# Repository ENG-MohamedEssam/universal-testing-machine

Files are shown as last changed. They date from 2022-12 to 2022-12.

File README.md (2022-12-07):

# universal-testing-machine

## **Abstract**
#### This projet at first was about Reverse-Engineering a Stress/Strain analysis machine, then fix it and Automate it's process.
#### The following is an image of the machine 
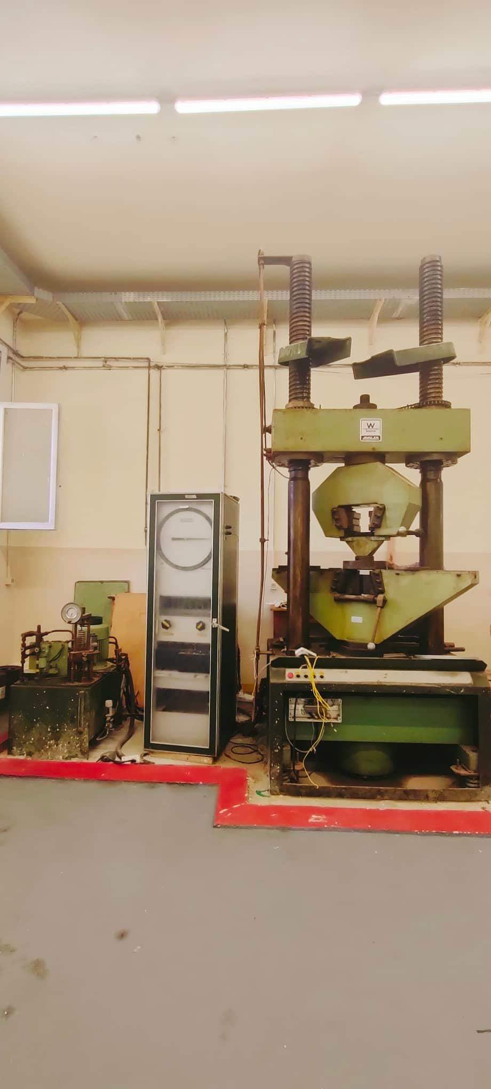
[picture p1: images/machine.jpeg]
Machine


#### Every part of the machine was Reverse-Engineered from the boards to the hydraulics to the classic control.
#### The following is an image of one of the Reverse-Engineered boards which was mine to Reverese-Engineer.
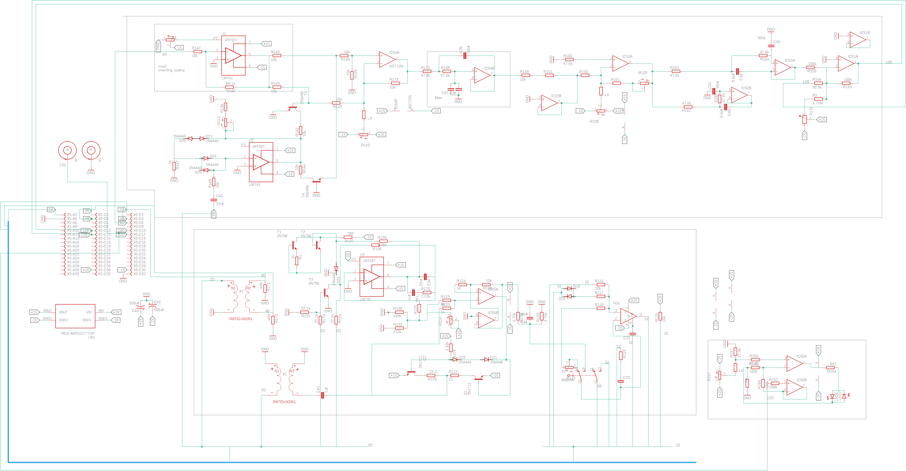
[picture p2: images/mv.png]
Board

#### I reverse Engineered The MV3058

#### Due to financial and permits issues the project was turned to be a prototype working with Embedded Systems.

#### The following is an image of the Prototype
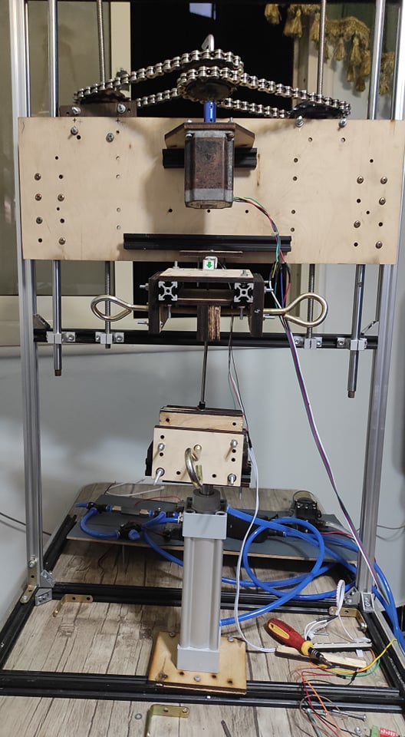
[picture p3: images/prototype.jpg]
prototype


#### The boards were desiged as follows, one board for the control, the second as a relay module. 

## **How the prototype works?**
 
#### The prototype mainly does exactly what the original machine does but on a smaller scale.
#### we mainly put a specimen between the two grippers and the machine puts tension or compression on the specimen till it breaks 
#### then it draws the Stress/Strain curves of the specimen's material.
#### It has a stepper motor used to adjust the place of the speciment, 
#### a piston that's derived by a hydraulic pump, 
#### a gripper used to grab the specimen.
#### As far as the Embedded systems part is concerend the machine had mainly 2 sensors ,
#### The Load Cell that's used to measure the Force and the Linear potentiometer that's used to measer the delta L.
#### the prototype is based mainly on two equations, Stress equation and Strain equation.
#### σ = F/A   ,    ε = δ/L  
#### the only two variables in these equations are the Force and the change in the length 

#### The following is images of the boards and panel.
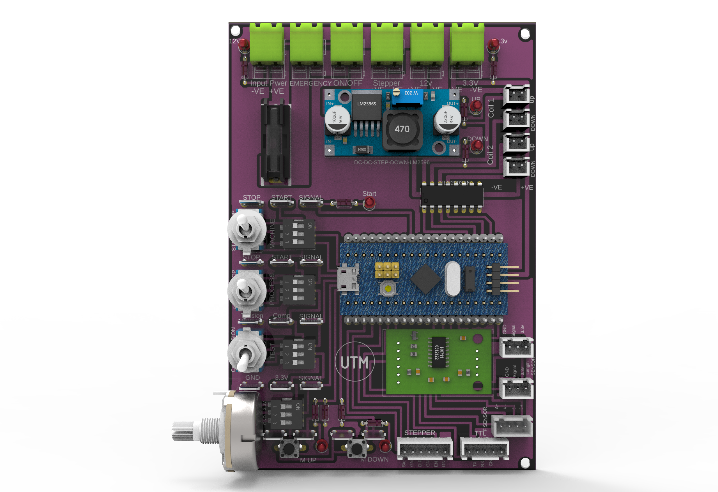
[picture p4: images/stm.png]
board

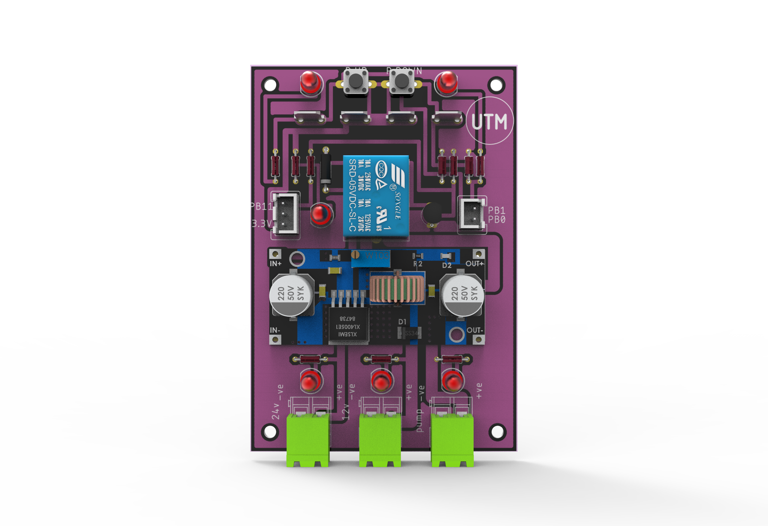
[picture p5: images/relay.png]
relay

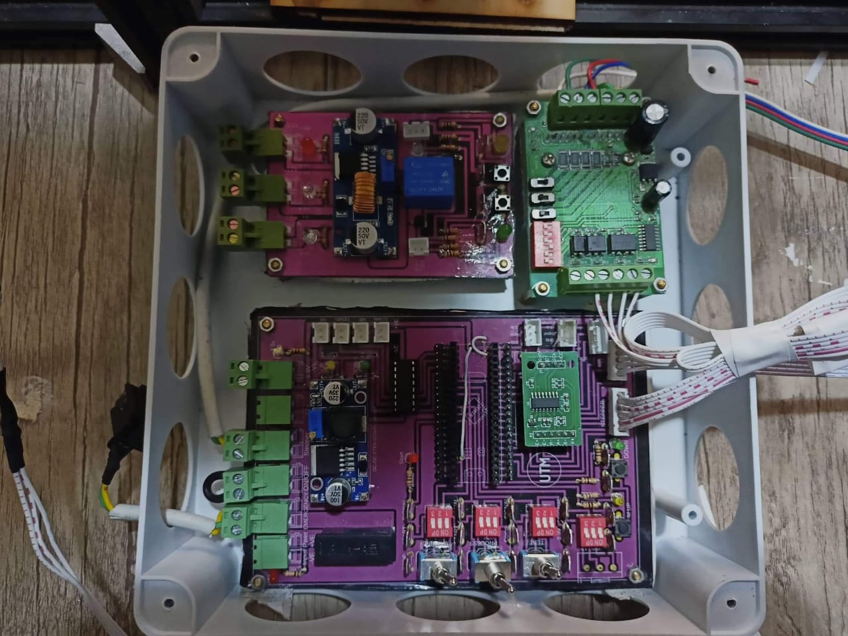
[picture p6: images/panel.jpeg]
panel


#### The follwing is Single Line Diagram that was made by me , it'll give you a good overview of all the Hardware connections in the panel
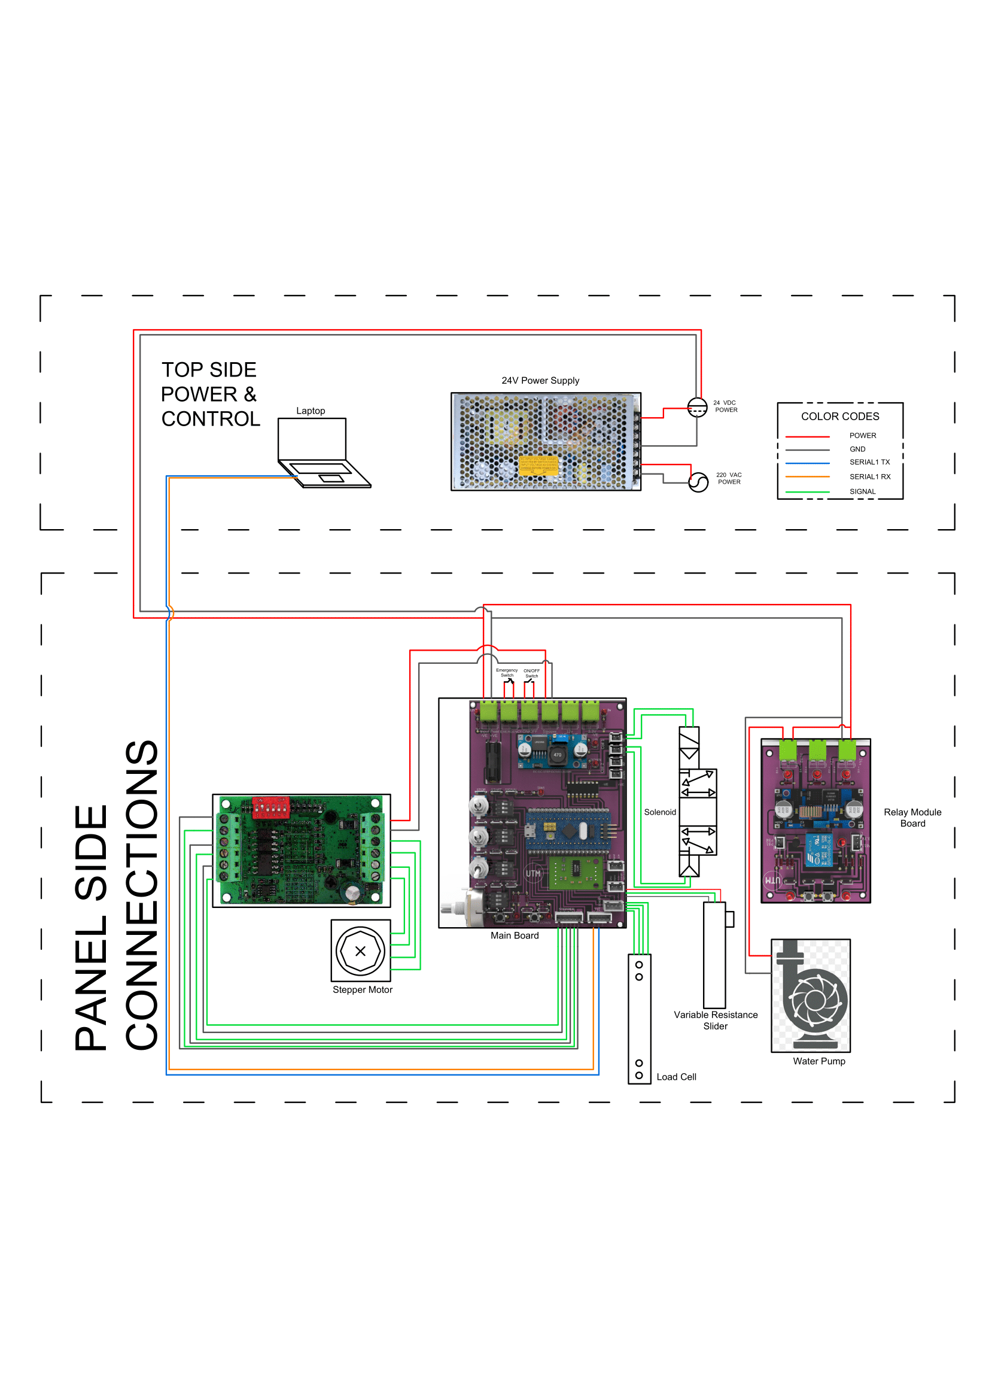
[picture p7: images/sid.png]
SID


#### The following link has some small SolidWorks parts that i've made for the machine whether it was as a specimen or for the sensors housings 
#### [parts](https://github.com/ENG-MohamedEssam/universal-testing-machine/tree/main/other-files/parts)

#### The following link has an explanation of the Embedded systems part explained by me 
#### [Explanation](https://drive.google.com/file/d/1bGaOVOjb-tQGSpPLI7ITkfYBf-VQDN8E/view)

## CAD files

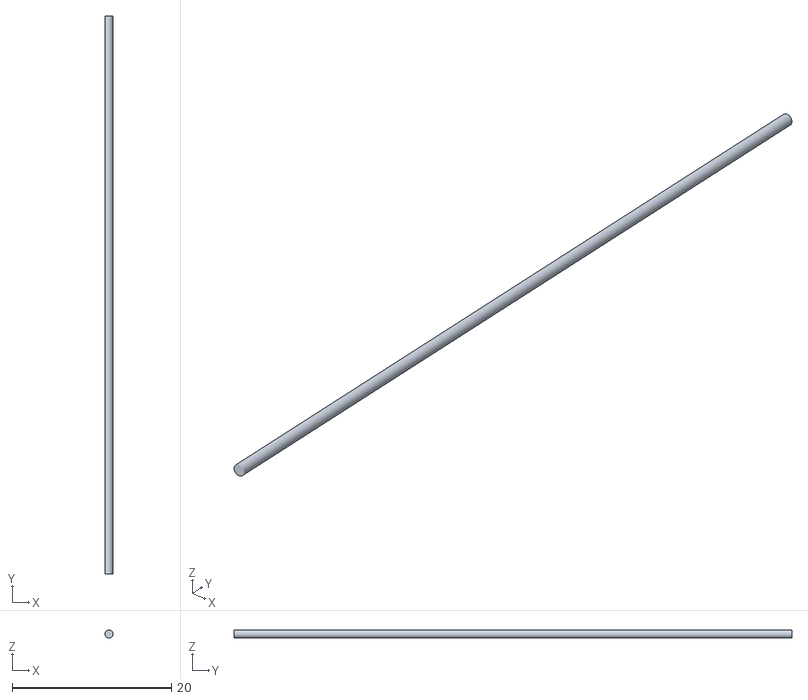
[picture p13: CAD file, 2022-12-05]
other-files/parts/Speciment round 7cm - 1mm.STL
0.999 x 70.0 x 1.00

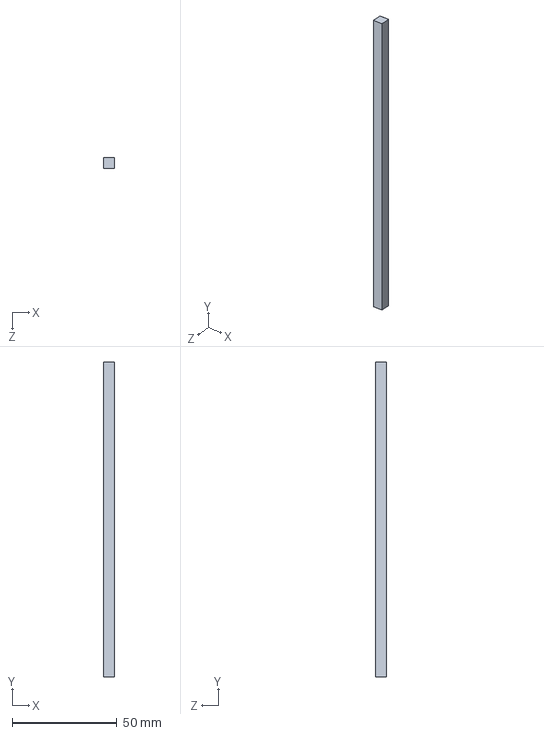
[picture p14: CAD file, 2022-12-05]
other-files/parts/Sample.SLDPRT
5.00 x 150.0 x 5.00 mm

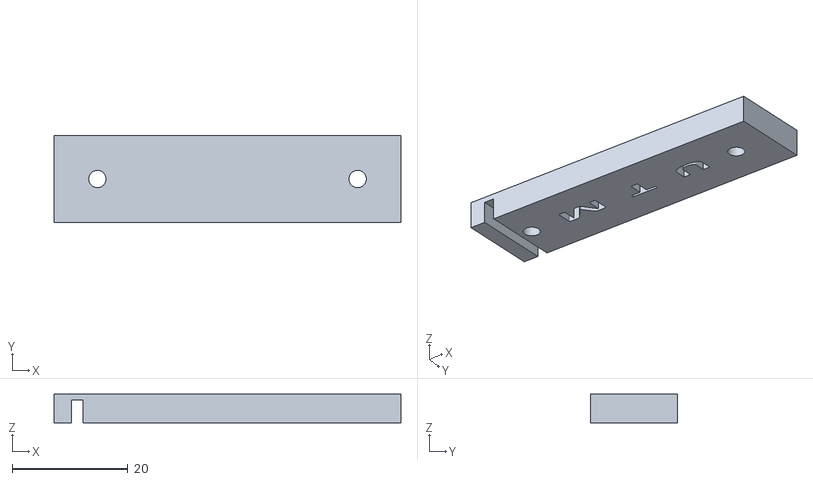
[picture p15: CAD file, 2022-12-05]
other-files/parts/UTM1.STL
60.0 x 15.0 x 5.00

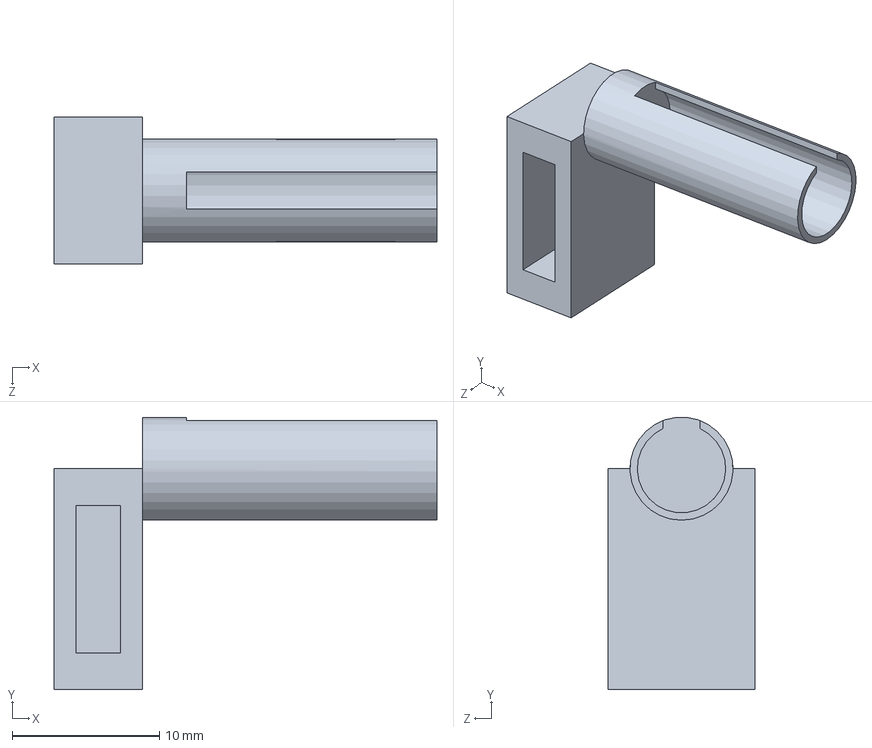
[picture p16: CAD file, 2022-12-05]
other-files/parts/LsensorHolder.SLDPRT
26.0 x 18.5 x 10.0 mm

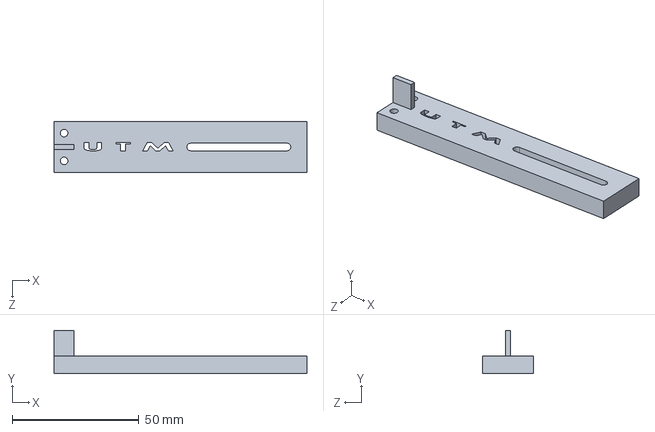
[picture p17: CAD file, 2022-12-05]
other-files/parts/Part2.SLDPRT
100.0 x 17.0 x 20.0 mm

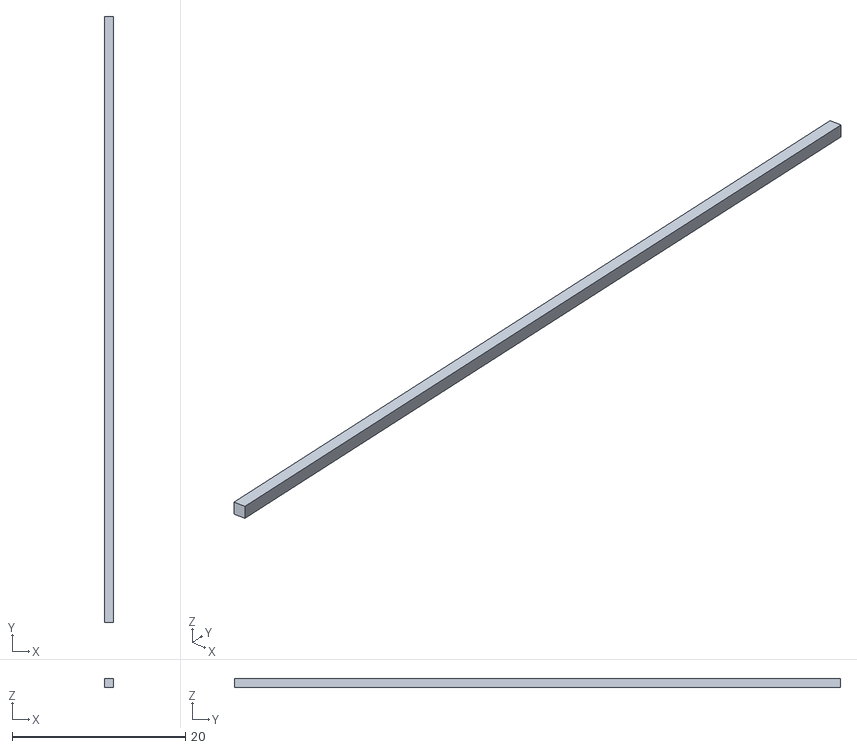
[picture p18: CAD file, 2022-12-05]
other-files/parts/Speciment square 7cm - 1mm.STL
1.00 x 70.0 x 1.00

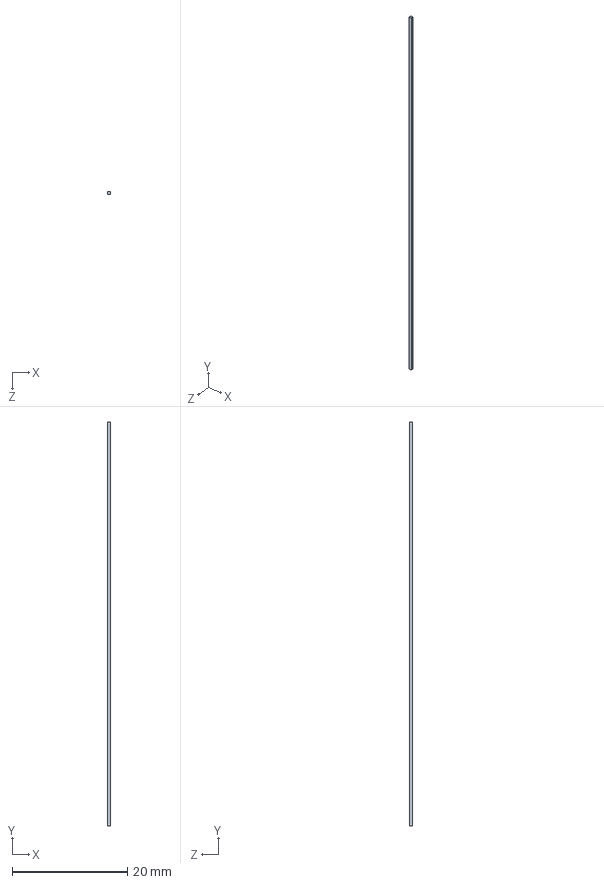
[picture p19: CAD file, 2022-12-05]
other-files/parts/Speciment round 7cm.SLDPRT
0.5 x 70.0 x 0.5 mm

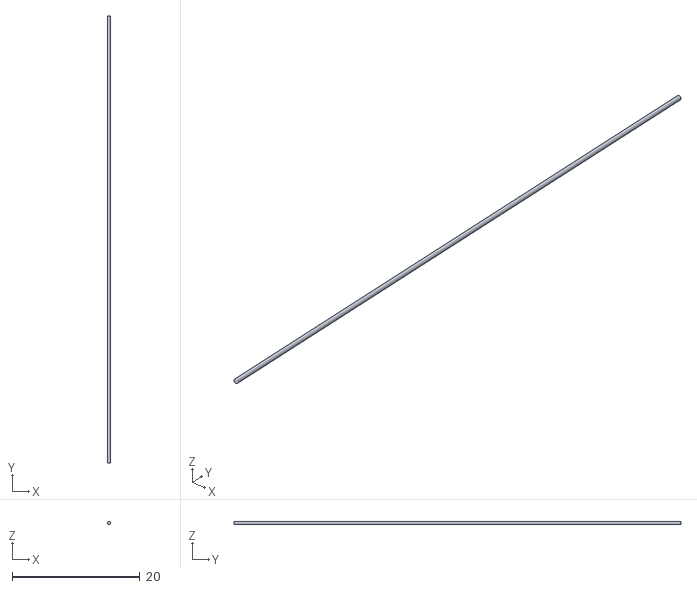
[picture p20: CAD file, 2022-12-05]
other-files/parts/Speciment round 7cm - 0.5mm .STL
0.5 x 70.0 x 0.5

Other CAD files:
other-files/SID.dwg
other-files/parts/Sample2.STL
other-files/parts/LsensorHolder.STL
other-files/parts/Part2.STL
other-files/parts/Sample.STL
other-files/parts/Speciment round 7cm - 0.5mm.STL

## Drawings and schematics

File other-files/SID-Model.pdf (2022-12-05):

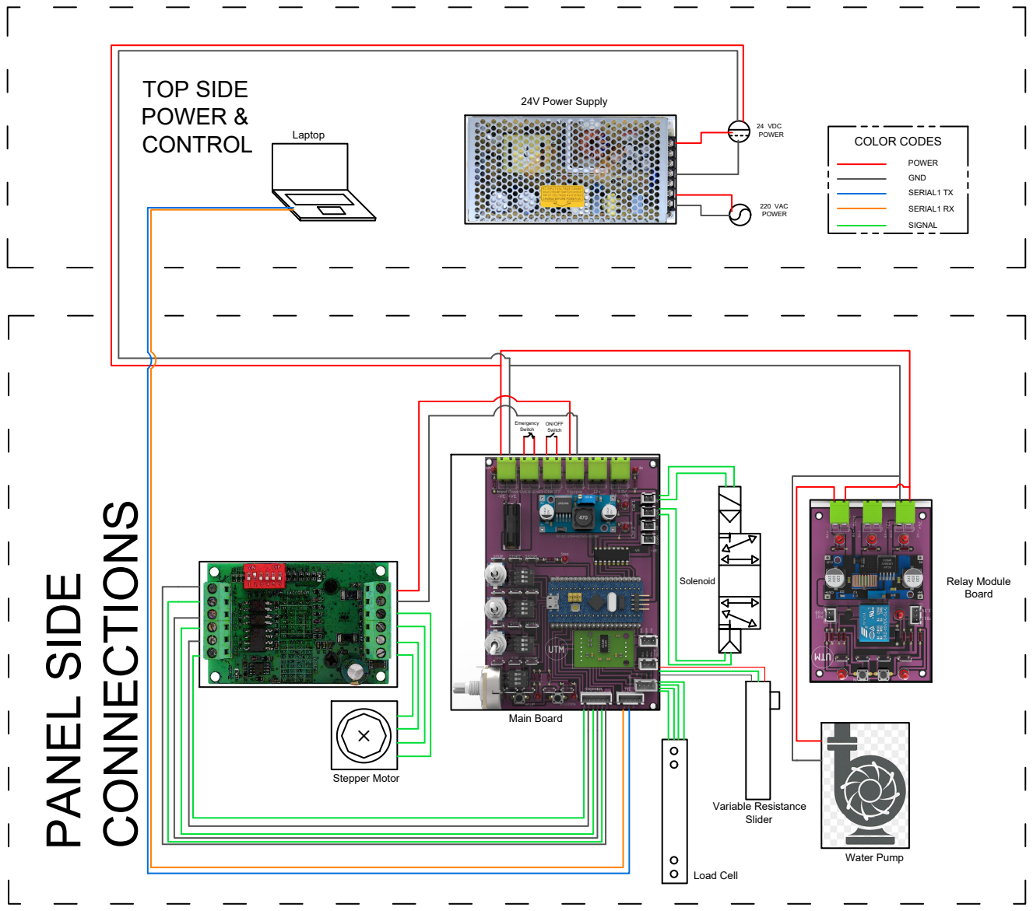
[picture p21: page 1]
COLOR CODES; POWER GND; SERIAL1 TX; SERIAL1 RX; 220 VAC; 24 VDC; TOP SIDE POWER &; Stepper Motor; Load Cell Variable Resistance Slider; Water Pump Main Board; Emergency Switch; ON/OFF Switch; 24V Power Supply

POWER PANEL SIDE CONNECTIONS

Relay Module Board Solenoid

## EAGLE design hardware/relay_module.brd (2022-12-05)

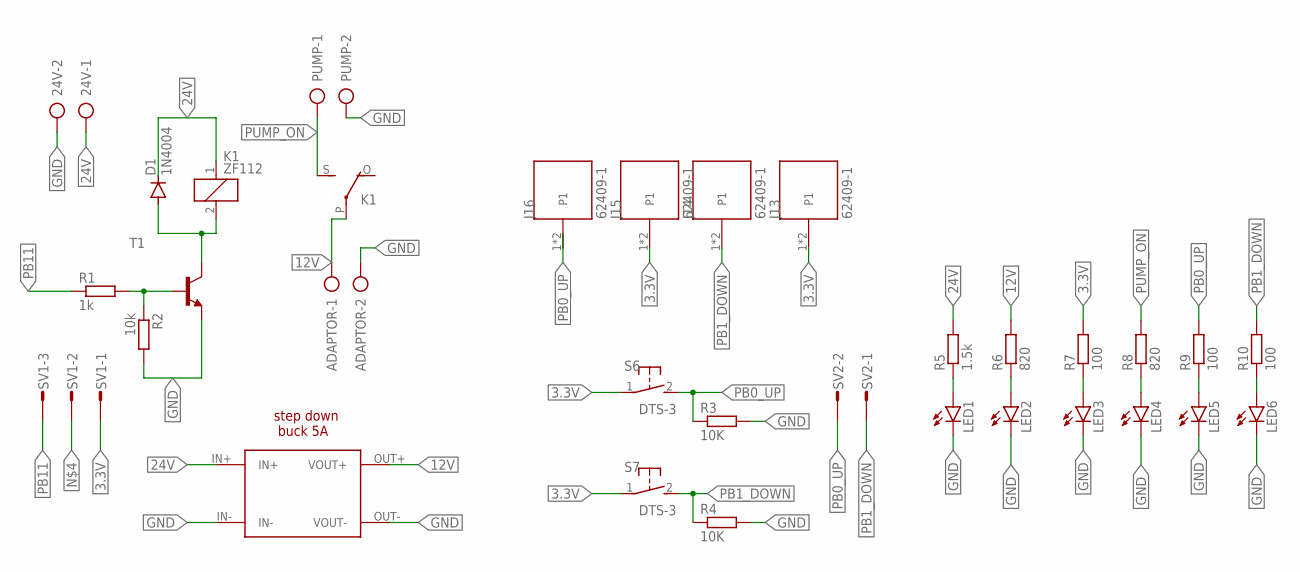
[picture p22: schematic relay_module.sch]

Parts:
24V: AK300/2
ADAPTOR: AK300/2
D1: 1N4004; DO41-10
J13, J14, J15, J16: 62409-1; TE_62409-1
K1: ZF112
LED1, LED2, LED3, LED4, LED5, LED6: LED5MM
PUMP: AK300/2
R1: 1k; 0204/7
R2: 10k; 0204/7
R3, R4: 10K; 0204/7
R5: 1.5k; 0204/7
R6, R8: 820; 0204/7
R7, R9, R10: 100; 0204/7
S6, S7: DTS-3
SV1: CON-AMP-MT_S03P
SV2: CON-AMP-MT_S02P
T1: 2N2222-NPN-TO92-EBC; TO92-EBC
U$1: BUCK_5A

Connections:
3.3V: J13.1, J13.2, J15.1, J15.2, R7.2, S6.1, S7.1, SV1.1
12V: ADAPTOR.1, K1.P, R6.2, U$1.OUT+ (VOUT+)
24V: 24V.1, D1.C, K1.1, R5.2, U$1.IN+
GND: 24V.2, ADAPTOR.2, LED1.K (C), LED2.K (C), LED3.K (C), LED4.K (C), LED5.K (C), LED6.K (C), PUMP.2, R2.2, R3.2, R4.2, T1.E, U$1.IN-, U$1.OUT- (VOUT-)
unnamed: R1.2, R2.1, T1.B
unnamed: LED1.A, R5.1
unnamed: D1.A, K1.2, T1.C
unnamed: LED2.A, R6.1
unnamed: LED5.A, R9.1
unnamed: LED3.A, R7.1
unnamed: LED4.A, R8.1
unnamed: LED6.A, R10.1
PB0_UP: J16.1, J16.2, R3.1, R9.2, S6.2, SV2.2
PB1_DOWN: J14.1, J14.2, R4.1, R10.2, S7.2, SV2.1
PB11: R1.1, SV1.3
PUMP_ON: K1.S, PUMP.1, R8.2

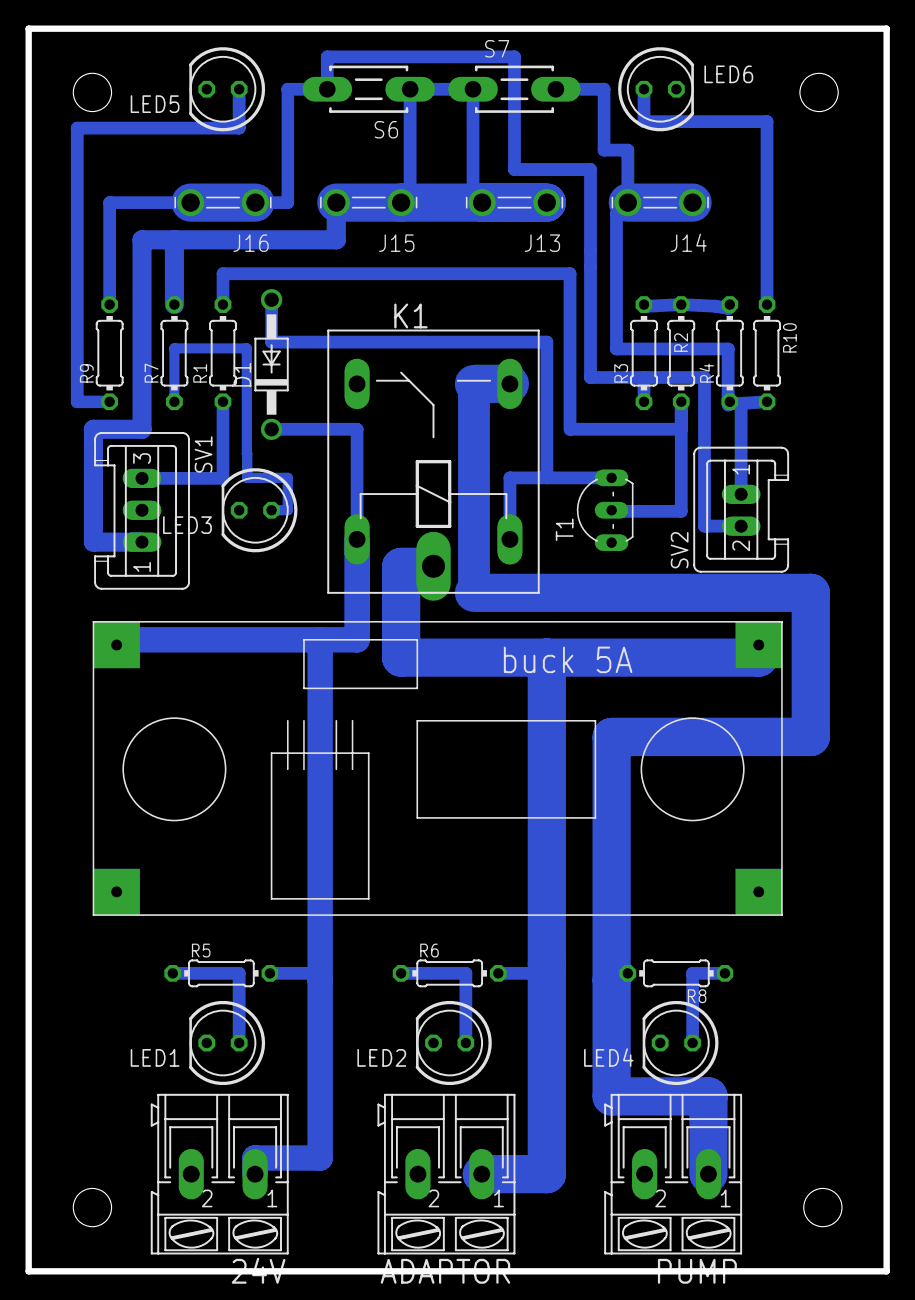
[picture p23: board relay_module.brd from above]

Board: 2 copper layers, 67.3 x 97.5 mm, 31 parts (0 on the bottom side), 16 nets.

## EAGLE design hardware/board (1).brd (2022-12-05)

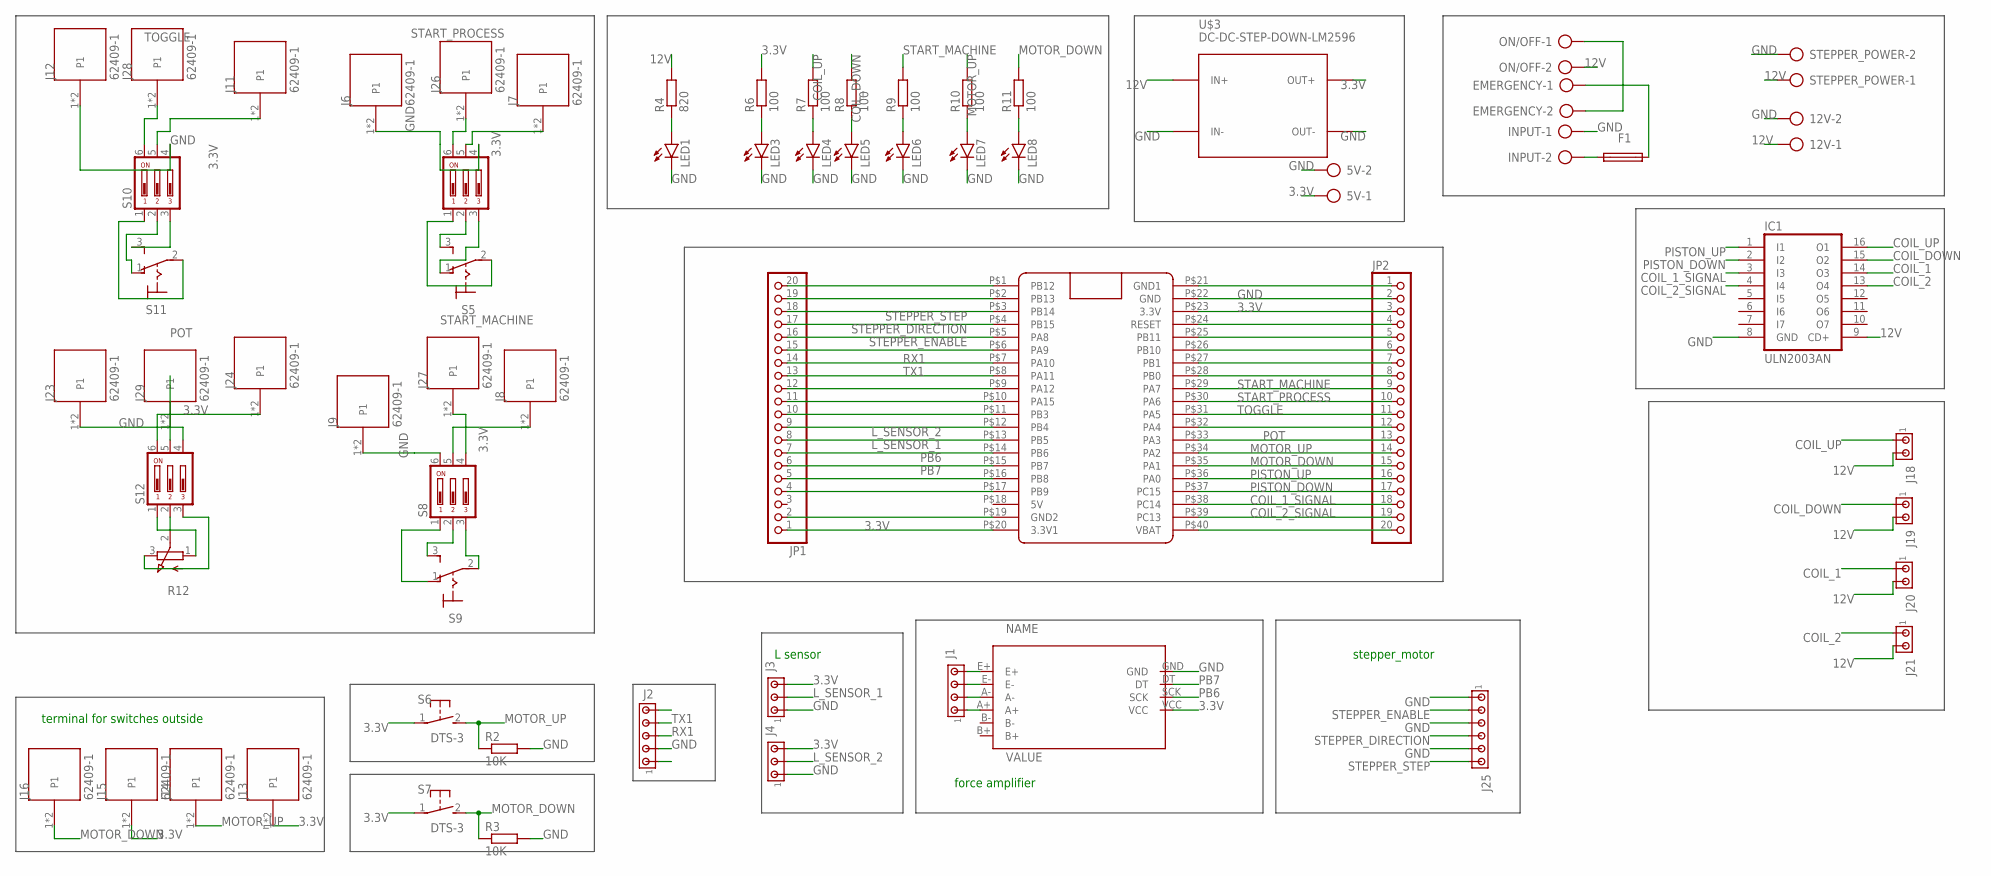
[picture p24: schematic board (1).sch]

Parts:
5V, 12V: AK300/2
EMERGENCY: AK300/2
F1: SH22
IC1: ULN2003AN; DIL16
INPUT: AK300/2
J1: MTA04-100; 10X04MTA
J2: MTA05-100; 10X05MTA
J3, J4: MTA03-100; 10X03MTA
J6, J7, J8, J9, J11, J12, J13, J14, J15, J16, J23, J24, J26, J27, J28, J29: 62409-1; TE_62409-1
J18, J19, J20, J21: MTA02-100; 10X02MTA
J25: MTA06-100; 10X06MTA
JP1, JP2: PINHD-1X20; 1X20
LED1, LED3, LED4, LED5, LED6, LED7, LED8: LED3MM
ON/OFF: AK300/2
R2, R3: 10K; 0204/7
R4: 820; 0204/7
R6, R7, R8, R9, R10, R11: 100; 0204/7
R12: 3RP/1610N
S4, S8, S10, S12: DP03; DP-03
S5, S9, S11: 320-916
S6, S7: DTS-3
STEPPER_POWER: AK300/2
U$1: BLUE_PILL
U$2: HX711A; HX711
U$3: DC-DC-STEP-DOWN-LM2596

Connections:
3.3V: 5V.1, J3.3, J4.3, J7.1, J7.2, J8.1, J8.2, J11.1, J11.2, J13.1, J13.2, J15.1, J15.2, J24.1, J24.2, JP1.1, JP2.3, R6.2, S4.5, S6.1, S7.1, S8.5, S10.5, S12.6, U$1.P$20 (3.3V1), U$1.P$23 (3.3V), U$2.VCC, U$3.OUT+
12V: 12V.1, IC1.9 (CD+), J18.2, J19.2, J20.2, J21.2, ON/OFF.2, R4.2, STEPPER_POWER.1, U$3.IN+
COIL_1: IC1.14 (O3), J20.1
COIL_1_SIGNAL: IC1.3 (I3), JP2.18, U$1.P$38 (PC14)
COIL_2: IC1.13 (O4), J21.1
COIL_2_SIGNAL: IC1.4 (I4), JP2.19, U$1.P$39 (PC13)
COIL_DOWN: IC1.15 (O2), J19.1, R8.2
COIL_UP: IC1.16 (O1), J18.1, R7.2
GND: 5V.2, 12V.2, IC1.8 (GND), INPUT.1, J2.2, J3.1, J4.1, J6.1, J6.2, J9.1, J9.2, J12.1, J12.2, J23.1, J23.2, J25.1, J25.3, J25.5, JP1.2, JP2.2, LED1.K (C), LED3.K (C), LED4.K (C), LED5.K (C), LED6.K (C), LED7.K (C), LED8.K (C), R2.2, R3.2, S4.4, S8.6, S10.4, S12.4, STEPPER_POWER.2, U$1.P$19 (GND2), U$1.P$22 (GND), U$2.GND, U$3.IN-, U$3.OUT-
L_SENSOR_1: J3.2, JP1.8, U$1.P$13 (PB5)
L_SENSOR_2: J4.2, JP1.9, U$1.P$12 (PB4)
MOTOR_DOWN: J16.1, J16.2, JP2.15, R3.1, R11.2, S7.2, U$1.P$35 (PA1)
MOTOR_UP: J14.1, J14.2, JP2.14, R2.1, R10.2, S6.2, U$1.P$34 (PA2)
unnamed: J1.4, U$2.E+
unnamed: J1.3, U$2.E-
unnamed: J1.2, U$2.A-
unnamed: J1.1, U$2.A+
unnamed: LED1.A, R4.1
unnamed: LED3.A, R6.1
unnamed: LED4.A, R7.1
unnamed: LED5.A, R8.1
unnamed: LED6.A, R9.1
unnamed: LED7.A, R10.1
unnamed: LED8.A, R11.1
unnamed: F1.1, INPUT.2
unnamed: S4.1, S5.2
unnamed: S4.2, S5.3 (S)
unnamed: JP1.4, U$1.P$17 (PB9)
unnamed: JP1.5, U$1.P$16 (PB8)
unnamed: JP1.10, U$1.P$11 (PB3)
unnamed: JP1.11, U$1.P$10 (PA15)
unnamed: JP1.12, U$1.P$9 (PA12)
unnamed: JP1.13, U$1.P$8 (PA11)
unnamed: EMERGENCY.1, F1.2
unnamed: EMERGENCY.2, ON/OFF.1
unnamed: JP2.20, U$1.P$40 (VBAT)
unnamed: JP2.7, U$1.P$27 (PB1)
unnamed: JP2.8, U$1.P$28 (PB0)
unnamed: JP1.20, U$1.P$1 (PB12)
unnamed: JP1.19, U$1.P$2 (PB13)
unnamed: S4.3, S5.1 (O)
unnamed: S10.1, S11.2
unnamed: S8.3, S9.2
unnamed: S8.1, S9.1 (O)
unnamed: JP2.1, U$1.P$21 (GND1)
unnamed: JP2.4, U$1.P$24 (RESET)
unnamed: S8.2, S9.3 (S)
unnamed: S10.3, S11.3 (S)
unnamed: S10.2, S11.1 (O)
unnamed: JP2.6, U$1.P$26 (PB10)
unnamed: R12.3 (E), S12.3
unnamed: R12.1 (A), S12.1
unnamed: R12.2 (S), S12.2
unnamed: JP2.12, U$1.P$32 (PA4)
unnamed: JP2.5, U$1.P$25 (PB11)
PB6: JP1.7, U$1.P$14 (PB6), U$2.SCK
PB7: JP1.6, U$1.P$15 (PB7), U$2.DT
PISTON_DOWN: IC1.2 (I2), JP2.17, U$1.P$37 (PC15)
PISTON_UP: IC1.1 (I1), JP2.16, U$1.P$36 (PA0)
POT: J29.1, J29.2, JP2.13, S12.5, U$1.P$33 (PA3)
RX1: J2.3, JP1.15, U$1.P$6 (PA9)
START_MACHINE: J27.1, J27.2, JP2.9, R9.2, S8.4, U$1.P$29 (PA7)
START_PROCESS: J26.1, J26.2, JP2.10, S4.6, U$1.P$30 (PA6)
STEPPER_DIRECTION: J25.4, JP1.17, U$1.P$4 (PB15)
STEPPER_ENABLE: J25.2, JP1.16, U$1.P$5 (PA8)
STEPPER_STEP: J25.6, JP1.18, U$1.P$3 (PB14)
TOGGLE: J28.1, J28.2, JP2.11, S10.6, U$1.P$31 (PA5)
TX1: J2.4, JP1.14, U$1.P$7 (PA10)

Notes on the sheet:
force amplifier
stepper_motor
L sensor
terminal for switches outside

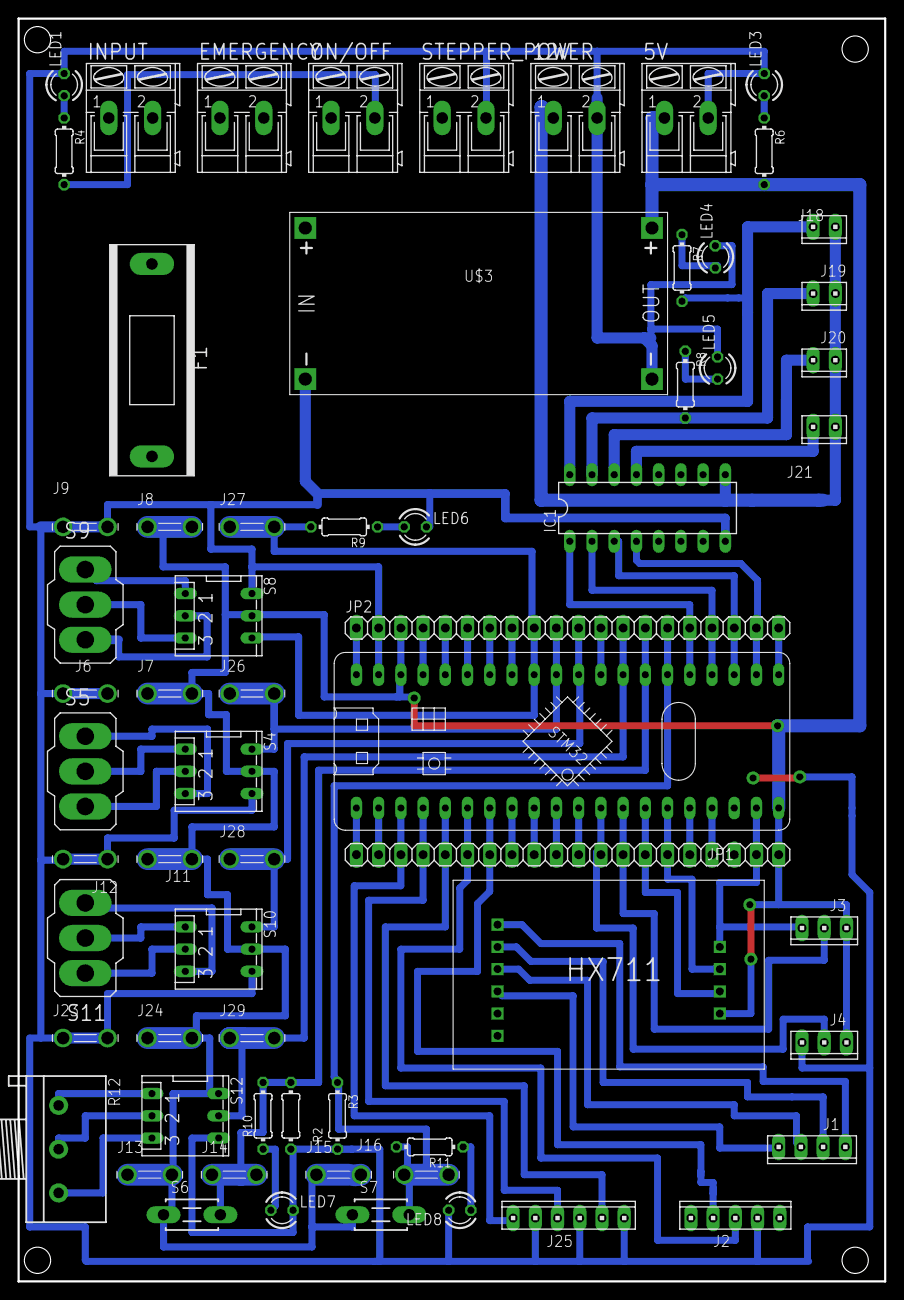
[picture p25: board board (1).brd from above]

Board: 2 copper layers, 99.0 x 144.3 mm, 64 parts (0 on the bottom side), 68 nets.

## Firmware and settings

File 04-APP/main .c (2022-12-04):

//*********************************************************************************/
/* Author    : Embedded system Sub team                                          */
/* Version   : V01                                                              */
/* Date      : 14 May 2020                                                     */
/******************************************************************************/

#include <stdio.h>
#include <stdlib.h>
#include "diag/Trace.h"


// Sample pragmas to cope with warnings. Please note the related line at
// the end of this function, used to pop the compiler diagnostics status.
#pragma GCC diagnostic push
#pragma GCC diagnostic ignored "-Wunused-parameter"
#pragma GCC diagnostic ignored "-Wmissing-declarations"
#pragma GCC diagnostic ignored "-Wreturn-type"
/******** includes Section **********/
#include "STD_TYPES.h"
#include "BIT_MATH.h"
#include "MCAL/RCC_interface.h"
#include "MCAL/DIO_interface.h"
#include "MCAL/USART_interface.h"
#include "MCAL/STK_interface.h"
#include "HAL/HX7111_force_sensor.h"
#include "HAL/STEPPER_HAL.h"
#include "MCAL/ADC_interface.h"
//------------------Macros---------
#define START_M             PIN7               // On or high (Toggle)     GPIOA
#define MOTOR_UP            PIN2               // normal push button      GPIOA
#define MOTOR_DOWN          PIN1               // normal push button      GPIOA
#define START_PROCESS       PIN6               //Toggle                   GPIOA
#define TOGGLE              PIN5               // tension or compression  GPIOA
#define PUMB_UP             PIN1               // pump (port B)
#define PUMB_DWON           PIN2               // pump (port B)
//-----------------------------
#define PISTON_UP      PIN0
#define PISTON_DOWN    PIN10
/*************************************/
//-----------------global variables -------
extern u8 global_u8ReceivedData;
float force;
float DeltaLength;
float Area = 125;   //mm2
float length = 70;   // meter
float Stress;
float Strain;
u8 X_axis[100];
u8 Y_axis[100];
int Gcount=0;
char breakpoint = 0;
char val1=0;
u8 flag=0;
/************************************/


/******************* Functions *********************/
void Fault_fun(void)
{
//	TOG_BIT(flag , 0);
//	MGPIO_VidSetPinValue(GPIOA,PIN10,flag);

}

void adjustmotor_UP()
{
	if(MGPIO_u8GetPinValue ( GPIOA , MOTOR_UP))
	{
		STEPPER_FORWARD(GPIOB, PIN14, GPIOB, PIN15,5000); //range time delay from 50 to 1000
	}

	else
	{
		STEPPER_stop(GPIOB, PIN14, GPIOB, PIN15);
	}
}


void adjustmotor_DOWN()
{

   if(MGPIO_u8GetPinValue ( GPIOA , MOTOR_DOWN))
	{
		STEPPER_REVERSE(GPIOB, PIN14, GPIOB, PIN15,5000);
	}
	else
	{
		STEPPER_stop(GPIOB, PIN14, GPIOB, PIN15);
	}
}


void selnoid_UP(){
 	MGPIO_VidSetPinValue(GPIOB, PISTON_UP, HIGH);
    MGPIO_VidSetPinValue(GPIOB, PISTON_DOWN, LOW);
    MSTK_voidSetBusyWait(300000);// 0.3 sec
 	MGPIO_VidSetPinValue(GPIOB, PISTON_UP, LOW);
    MGPIO_VidSetPinValue(GPIOB, PISTON_DOWN, LOW);
}
void selnoid_DWON(){
 	MGPIO_VidSetPinValue(GPIOB, PISTON_UP, LOW);
    MGPIO_VidSetPinValue(GPIOB, PISTON_DOWN, HIGH);
    MSTK_voidSetBusyWait(300000);// 0.3 sec
 	MGPIO_VidSetPinValue(GPIOB, PISTON_UP, LOW);
    MGPIO_VidSetPinValue(GPIOB, PISTON_DOWN, LOW);
}

void switches_int(void)
{

	MGPIO_VidSetPinDirection(GPIOA,START_M,INPUT_FLOATING);
	MGPIO_VidSetPinDirection(GPIOA,MOTOR_UP,INPUT_FLOATING);
	MGPIO_VidSetPinDirection(GPIOA,MOTOR_DOWN,INPUT_FLOATING);
	MGPIO_VidSetPinDirection(GPIOA,START_PROCESS,INPUT_FLOATING);
	MGPIO_VidSetPinDirection(GPIOA,TOGGLE,INPUT_FLOATING);

	MGPIO_VidSetPinDirection(GPIOA,PUMB_UP,INPUT_FLOATING);// NEW: port B
	MGPIO_VidSetPinDirection(GPIOA,PUMB_DWON,INPUT_FLOATING);

	MGPIO_VidSetPinDirection(GPIOA,PISTON_UP,OUTPUT_SPEED_10MHZ_PP); //for  pump Up
	MGPIO_VidSetPinDirection(GPIOB,PISTON_DOWN,OUTPUT_SPEED_10MHZ_PP);//for pump down

}

void Compression ()
{  	MGPIO_VidSetPinValue(GPIOB, PISTON_UP, HIGH);
MGPIO_VidSetPinValue(GPIOB, PISTON_DOWN, LOW);
MSTK_voidSetBusyWait(100);
force = ADC_u16ReadChannelPoll(1);
while(force>10 && MGPIO_u8GetPinValue(GPIOA,TOGGLE))
{

	force = ADC_u16ReadChannelPoll(1);
	DeltaLength = ADC_u16ReadChannelPoll(4);
	Stress  = force / Area;  //stress eqn
	Strain  = DeltaLength / length; // srain eqn
	X_axis[Gcount] = (char) Stress * 10;             //i.e. 1.4*10 = 14
	Y_axis[Gcount] = (char) Strain * 10;
	Gcount++;
}
for(int i=0; i<=Gcount; i++){
	MUSART1_voidTransmit(&X_axis[i],1);
	MUSART1_voidTransmit(&Y_axis[i],1);
}
Gcount =0 ;
breakpoint = 1;
}


void Tension(void)
{
	MGPIO_VidSetPinValue(GPIOB, PISTON_UP, LOW);
	MGPIO_VidSetPinValue(GPIOB, PISTON_DOWN, HIGH);
	MSTK_voidSetBusyWait(100);
	force = ADC_u16ReadChannelPoll(1);
	while(force>10 && MGPIO_u8GetPinValue(GPIOA,TOGGLE))
	{

		force = ADC_u16ReadChannelPoll(1);
		DeltaLength = ADC_u16ReadChannelPoll(4);
		Stress  = force / Area;  //stress eqn
		Strain  = DeltaLength / length; // srain eqn
		X_axis[Gcount] = (char) Stress * 10;             //i.e. 1.4*10 = 14
		Y_axis[Gcount] = (char) Strain * 10;
		Gcount++;
	}
	for(int i=0; i<=Gcount; i++){
		MUSART1_voidTransmit(&X_axis[i],1);
		MUSART1_voidTransmit(&Y_axis[i],1);
	}
	Gcount =0 ;
	breakpoint = 1;

}



int main(int argc, char* argv[])
{

	// init preigherals and clocks

	RCC_voidInitSysClock();
	RCC_voidEnableClock(RCC_APB2,2);  // clocks for port A
	RCC_voidEnableClock(RCC_APB2,3);  // clocks for port B
	RCC_voidEnableClock(RCC_APB2,9);  // clocks for ADC1
	RCC_voidEnableClock(RCC_APB2,14); // clocks for UART1
	MSTK_voidInit();
	ADC_VoidInit();
	MUSART1_voidInit();
	//--------------------------------
	/* Setting A9:TX pin as Output alternate function push pull w max speed 50 MHz */
	MGPIO_VidSetPinDirection(GPIOA,PIN9,OUTPUT_SPEED_50MHZ_AFPP);
	/* Setting A10:RX pin as input floating */
	MGPIO_VidSetPinDirection(GPIOA,PIN10,OUTPUT_SPEED_2MHZ_PP);
	STEPPER_void_init(GPIOB,PIN14,GPIOB,PIN15);
    switches_int();
	MUSART1_voidSetcallBack(Fault_fun);
	u8 Recive_USART=0;
	while(1)
	{
		if(MGPIO_u8GetPinValue(GPIOA,START_M)){



			if(MGPIO_u8GetPinValue(GPIOA,MOTOR_UP) || global_u8ReceivedData == 1U ){

				adjustmotor_UP();
			}
			else if(MGPIO_u8GetPinValue(GPIOA,MOTOR_DOWN) || global_u8ReceivedData == 2U){

				adjustmotor_DOWN();
			}
			else if(MGPIO_u8GetPinValue(GPIOA,PUMB_UP) || global_u8ReceivedData == 3U){

				selnoid_UP();
			}
			else if(MGPIO_u8GetPinValue(GPIOA,PUMB_DWON) || global_u8ReceivedData == 4U){

				selnoid_DWON();
			}
			else if(MGPIO_u8GetPinValue(GPIOA,TOGGLE) || global_u8ReceivedData == 5U){   //Say compression

				Compression();
			}
			else if(!MGPIO_u8GetPinValue(GPIOA,TOGGLE) || global_u8ReceivedData == 6U){   //Say tension

					Tension();
			}

			else {
                   //Do nothing
			}





		}

	}



}
#pragma GCC diagnostic pop

//
// Recive_USART = MUSART1_u8Receive();
//		switch(Recive_USART){
//		case 1:
//			adjustmotor_UP();    // Move Stepper motor Up
//			break;
//		case 2:
//			adjustmotor_DWON();  // Move Stepper motor Up
//			break;
//		case 3:
//			break;
//		case 4:
//			break;
//		case 5:
//			break;
//
//
//
//
//
//	     	}

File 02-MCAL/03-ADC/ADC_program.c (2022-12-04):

#include "STD_TYPES.h"
#include "BIT_MATH.h"

#include "ADC_private.h"
#include "ADC_config.h"
#include "ADC_interface.h"

#include "RCC_private.h"
#include "DIO_private.h"
#include "NVIC_interface.h"
#include "systick_time.h"



void ADC_VoidInit(void)
{
	//RCC Clock for ADC1 and Altern. Func.
	SET_BIT(RCC_APB2ENR,0); // Enable AFIO
	SET_BIT(RCC_APB2ENR,2); // Enable I/O Port A
	SET_BIT(RCC_APB2ENR,9); // Enable ADC1

	/* Enable ADC Single Contineous mode*/
	SET_BIT(ADC1 -> CR2,0);
	SET_BIT(ADC1 -> CR2,1);
	DelayMs(1);

	/************ Choose Prescalar ************/
#if ADC_PRESCALAR == CLK_DIVIDE_BY_2
	CLR_BIT(RCC_CFGR,14);
	CLR_BIT(RCC_CFGR,15);
#elif ADC_PRESCALAR == CLK_DIVIDE_BY_4
	SET_BIT(RCC_CFGR,14);
	CLR_BIT(RCC_CFGR,15);

#elif ADC_PRESCALAR == CLK_DIVIDE_BY_6
	CLR_BIT(RCC_CFGR,14);
	SET_BIT(RCC_CFGR,15);
#else
	SET_BIT(RCC_CFGR,14);
	SET_BIT(RCC_CFGR,15);
#endif


#if ADC_SAMPLE_RATE == ADC_CYCLE_1
	ADC1 -> SMPR2 = 0x00000000;

#elif ADC_SAMPLE_RATE == ADC_CYCLE_7
	ADC1 -> SMPR2 = 0x09249249;

#elif ADC_SAMPLE_RATE == ADC_CYCLE_13
	ADC1 -> SMPR2 = 0x12492492;

#elif ADC_SAMPLE_RATE == ADC_CYCLE_28
	ADC1 -> SMPR2 = 0x1B6DB6DB;

#elif ADC_SAMPLE_RATE == ADC_CYCLE_41
	ADC1 -> SMPR2 = 0x24924924;

#elif ADC_SAMPLE_RATE == ADC_CYCLE_55
	ADC1 -> SMPR2 = 0x2DB6DB6D;

#elif ADC_SAMPLE_RATE == ADC_CYCLE_71
	ADC1 -> SMPR2 = 0x36DB6DB6;

#elif ADC_SAMPLE_RATE == ADC_CYCLE_239
	ADC1 -> SMPR2 = 0x3FFFFFFF;
#endif

	//Enable ADC for the first Time
	SET_BIT(ADC1 -> CR2,0); // SET ADON bit
	SET_BIT(ADC1 -> CR2,1); // use ADC in continuous Mode
	DelayMs(1); //  1m sec delay

	//Turn ADC on for the second Time
	SET_BIT(ADC1 -> CR2,0); // set ADON bit
	SET_BIT(ADC1 -> CR2,1);
	DelayMs(1); // 1 ms delay

	// Set calibration Bit
	SET_BIT(ADC1 -> CR2,2);
	DelayMs(2); //2 ms delay


}

u16 ADC_u16ReadChannelPoll(u16 Channel_u16Number)/* Channel Num from 0 to 9*/
{
	switch(Channel_u16Number)
	{
	case 0:
		// Analog Mode
		CLR_BIT(GPIOA_CRL,0);
		CLR_BIT(GPIOA_CRL,1);
		CLR_BIT(GPIOA_CRL,2);
		CLR_BIT(GPIOA_CRL,3);
		DelayMs(1);

		//Set the channel  for conversion 	( Channel 0 )
		CLR_BIT(ADC1 -> SQR3,0);
		CLR_BIT(ADC1 -> SQR3,1);
		CLR_BIT(ADC1 -> SQR3,2);
		CLR_BIT(ADC1 -> SQR3,3);
		while((ADC1 -> SR &(1<<1)) == 0);
		break;
	case 1:
		// Analog Mode
		CLR_BIT(GPIOA_CRL,4);
		CLR_BIT(GPIOA_CRL,5);
		CLR_BIT(GPIOA_CRL,6);
		CLR_BIT(GPIOA_CRL,7);
		DelayMs(1);

		//Set the channel  for conversion 	( Channel 1 )
		SET_BIT(ADC1 -> SQR3,0);
		CLR_BIT(ADC1 -> SQR3,1);
		CLR_BIT(ADC1 -> SQR3,2);
		CLR_BIT(ADC1 -> SQR3,3);
		while((ADC1 -> SR &(1<<1)) == 0);
		break;
	}
	return ADC1 -> DR;
}
/*
void ADC1_2_IRQHandler(void)
{
	u32 VAL = 0;
	// Check if the code reached here bec. end of conversion flag is set
	// End of conversion flag is cleared by reading the data register
	while(GET_BIT(ADC_SR,1) == 0);
	return VAL;
	if(ADC_u8CallBackPtr != NULL)
	{
		(*ADC_u8CallBackPtr)();
			MNVIC_voidDisableInterrupt(18);
	}
}

void ADC_voidSetCallBack(void(*ADC_u8Ptr)(void))
{
	ADC_u8CallBackPtr = ADC_u8Ptr;
}

u32 ADC_u32ReturnValue(void)
{
	return ADC1 -> DR;
}
*/

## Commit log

2022-12-05 Updating the images and some text in readme
    [board (1).brd, board (1).sch, relay_module.brd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]
2022-12-05 Some Edits in the text and images
    [MVSch5.sch, SID.dwg]
2022-12-05 Uploading SolidWorks parts and editing the readme file
    [LsensorHolder.SLDPRT, LsensorHolder.STL, Part2.SLDPRT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]

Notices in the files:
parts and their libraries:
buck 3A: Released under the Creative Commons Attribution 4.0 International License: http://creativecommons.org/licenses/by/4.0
